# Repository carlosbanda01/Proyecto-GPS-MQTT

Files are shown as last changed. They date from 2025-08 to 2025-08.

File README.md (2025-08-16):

# Proyecto-GPS-CBC

Se desarrolló una solución de monitoreo GPS en tiempo real basada en una PCB personalizada que integra módulos SIM, GPS, relés, controladores I2C para pantallas LCD, reguladores de voltaje, comunicación SPI y microcontroladores ESP32 de doble núcleo con RTOS. La transmisión de datos hacia el servidor se implementó mediante el protocolo MQTT. Como complemento, se diseñó una plataforma web para la consulta y visualización de los datos almacenados, ofreciendo un sistema integral para supervisar y gestionar el funcionamiento de los equipos en operación.

---

### 🖼️ Placa de PCB diseñada

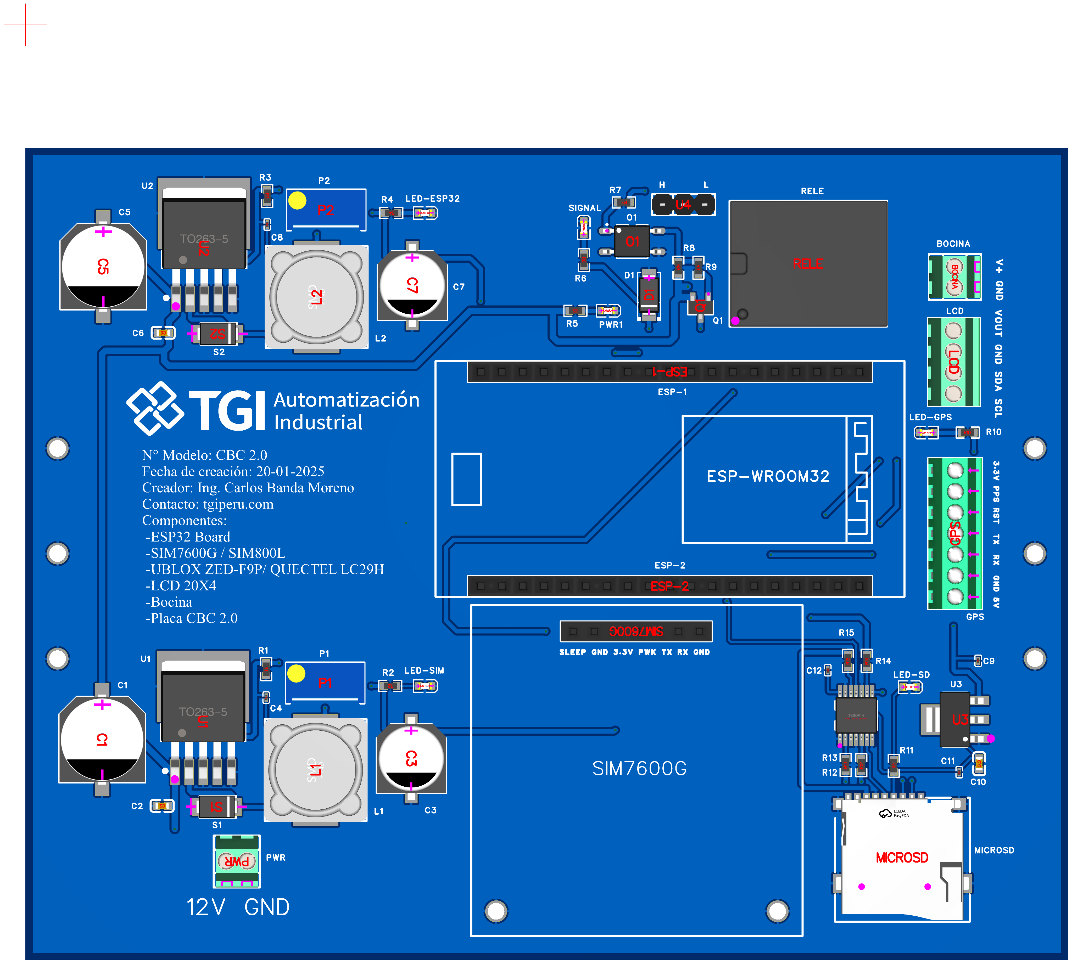
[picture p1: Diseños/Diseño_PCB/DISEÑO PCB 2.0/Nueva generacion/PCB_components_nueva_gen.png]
Diseño PCB Nueva Generación


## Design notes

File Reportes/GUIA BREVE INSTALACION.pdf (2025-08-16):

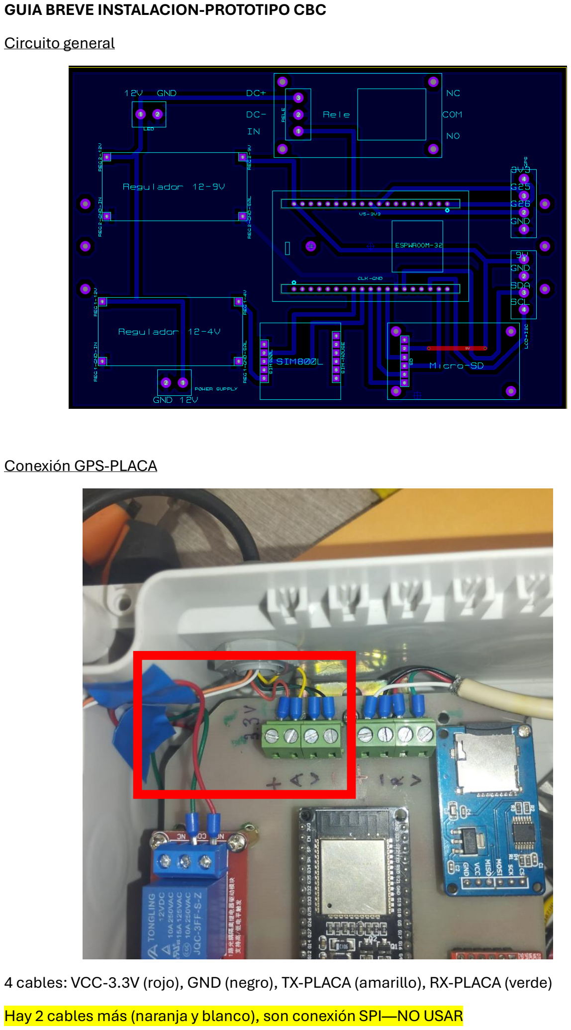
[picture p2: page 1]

GUIA BREVE INSTALACION-PROTOTIPO CBC Circuito general

Conexión GPS-PLACA

4 cables: VCC-3.3V (rojo), GND (negro), TX-PLACA (amarillo), RX-PLACA (verde) Hay 2 cables más (naranja y blanco), son conexión SPI—NO USAR

Conexión LCD-PLACA

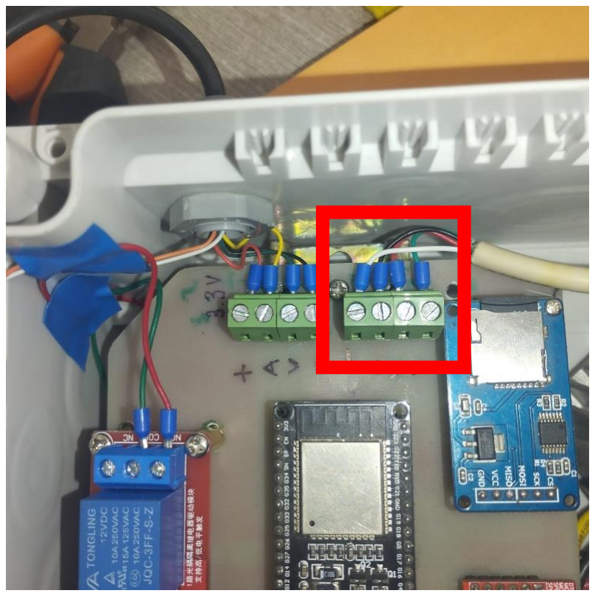
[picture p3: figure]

4 cables: VCC-(5-10)V (blanco), GND (negro). SDA (rojo) y SCL (verde)
En caso el cable quede muy largo, se sugiere cortar el cable por la parte cercana a la caja, pues NO SE RECOMIENDA abrir la caja metálica.
ASEGURARSE DE QUE LOS CABLES ESTEN FIJADOS A LAS BORNERAS
Conexión ALIMENTACIÓN-PLACA

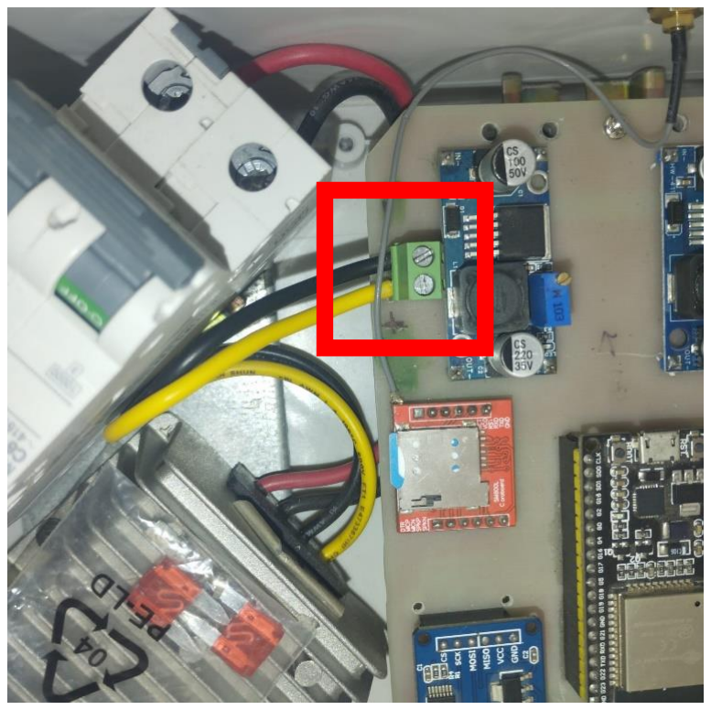
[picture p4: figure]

2 cables: VCC-12V (Amarillo) y GND (negro)
ASEGURARSE DE QUE LOS CABLES ESTEN FIJADOS A LAS BORNERAS

Conexión BUZZER-RELE-PLACA

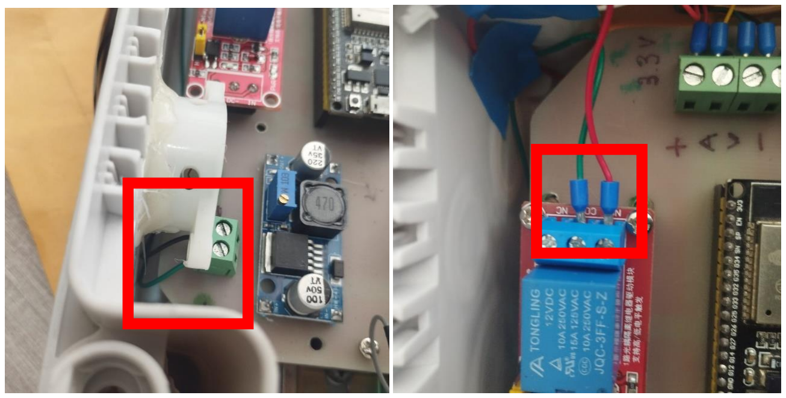
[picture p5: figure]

Del BUZZER hay 2 cables: VCC-(8-24V) (rojo) y GND (negro), el cable rojo del BUZZER se conecta a la bornera NO del RELÉ, por otro lado, el cable negro del BUZZER se conecta a la bornera verde superior de la PLACA.
ASEGURARSE DE QUE LOS CABLES ESTEN FIJADOS A LAS BORNERAS
Finalmente se conecta un cable verde que sirva como puente entre el positivo de la bornera verde de la PLACA con el COM del RELÉ.
Respecto al encendido del prototipo:
1. Encender el circuito
¿Qué se espera?
Que enciendan las 3 luces del circuito

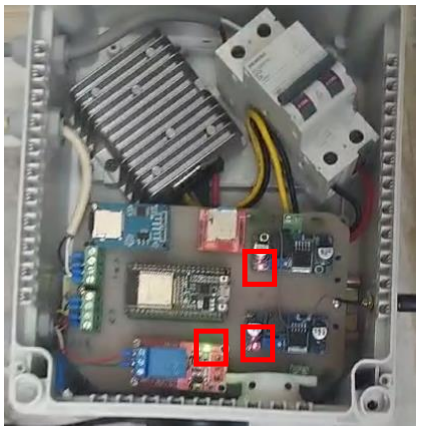
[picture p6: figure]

2. Activar la LCD
¿Qué se espera?
El mensaje de “Iniciando…” en el display seguido del mensaje “Esperando SIM800”

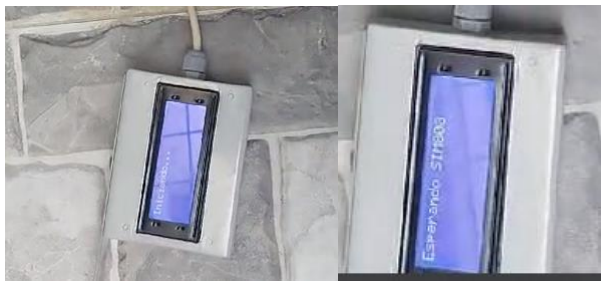
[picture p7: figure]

3. Activar el módulo SIM800L
¿Qué se espera?
El mensaje de “SIM800 iniciado” en el display

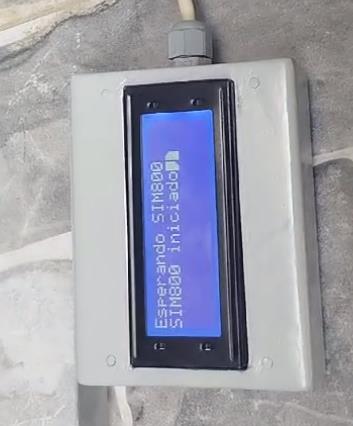
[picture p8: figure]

4. Conectarse a Internet (GPRS)
¿Qué se espera?
El mensaje de “Conectado a GPRS” en el display.
Normalmente este paso demora menos de 20 segundos en activarse, depende de la señal de la cobertura 2G, según la documentación de movistar en CBC toda el área tiene cobertura 2G.

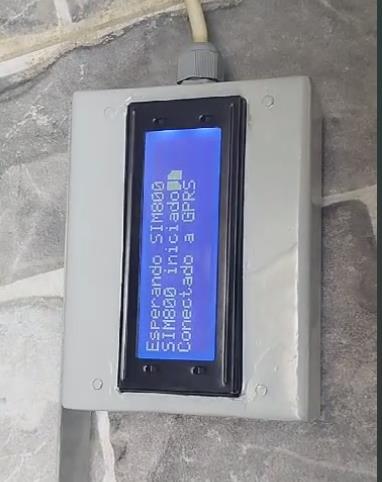
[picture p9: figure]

5. Conectarse al bróker ()
¿Qué se espera?
Recibir mensajes de modulo iniciado en el bróker. (un indicador verificable seria lo esperable del paso 6)
6. Activar la SD
¿Qué se espera?
El mensaje de “SD inicializada” en el display

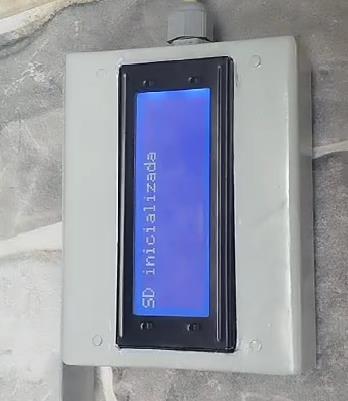
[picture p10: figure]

7. Conectarse a los satélites
¿Qué se espera?
Que desaparezca el mensaje de “Captando señal…” en el display
Normalmente este proceso demora entre 1-2 min cuando el prototipo se enciende tras mucho tiempo estar apagado.
8. Conectado
¿Qué se espera?
Que se muestre la velocidad (con una tasa de refresco de 1 segundo ) y que dichos datos se envíen al bróker mediante GPRS.

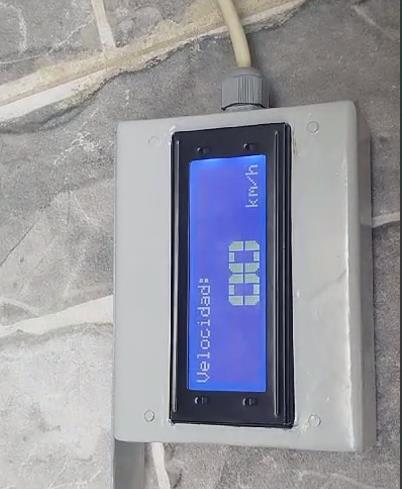
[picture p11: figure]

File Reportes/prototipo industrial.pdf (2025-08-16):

Presentación alternativas-Prototipo industrial CBC
1. PCB propia+ adaptadores Riel-DIN
PCB-propia
En lima se cuentan con servicios de impresión en PCB, en el software Proteus se puede diseñar las conexiones de la PCB con los componentes que ya se tienen y que irán dentro de la PCB (ESP32, REGULADOR DE VOLTAJE MODULO SIM7600G/800L, RELE, TARJETA microSD) como tal, además se contará con borneras para las conexiones con los componentes externos a la caja (GPS, PANTALLA LCD, BOCINA/LED que avise exceso de velocidad, FOCO LED que verifica energizado)

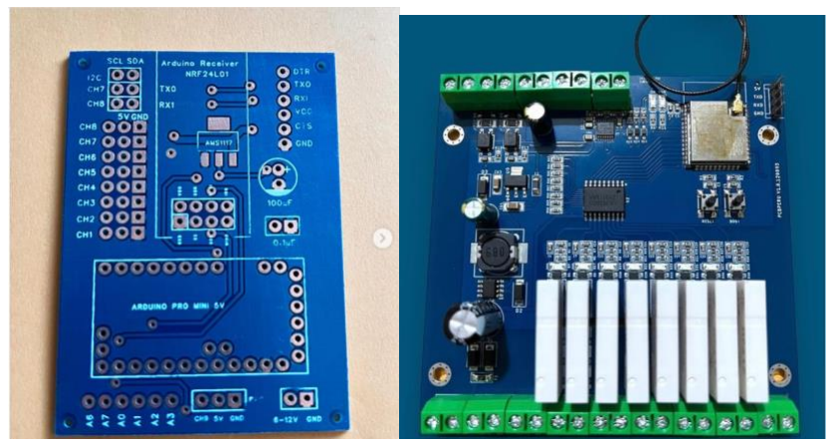
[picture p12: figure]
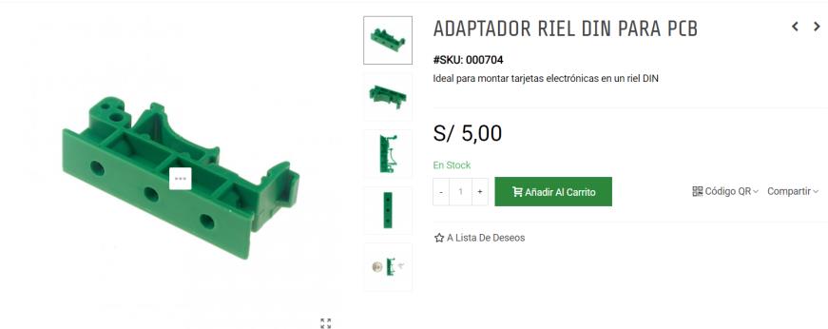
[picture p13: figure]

Cosas para considerar:
-Fácil acceso y compras que se pueden realizar rápido (todo está en stock y en lima) (a excepción del módulo SIM7600G)
-Es posible adquirir un módulo GNSS de menor generación como el SIM800L en Lima que son compatibles con el proyecto, sin embargo, este módulo funciona con cobertura 2G, que en un futuro será obsoleta y retirada.

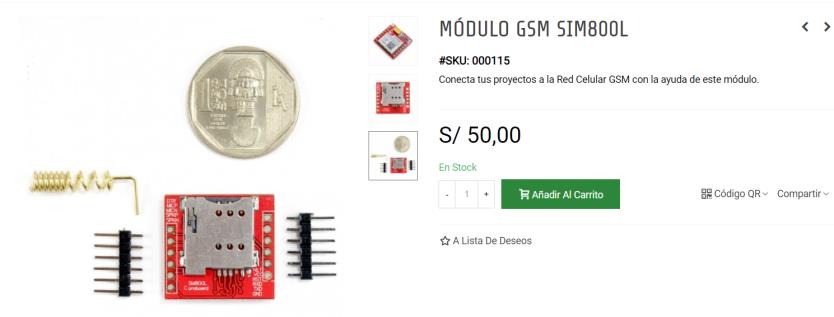
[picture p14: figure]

-Para conseguir el módulo SIM7600 o módulos similares se debe pedir y esperar durante un buen tiempo.
-Los módulos de última generación como los SIM7600,SIM7100C,SIM7670 y la lista sigue por mucho, algunos traen integrados ya en sus módulos comerciales, receptores GPS.

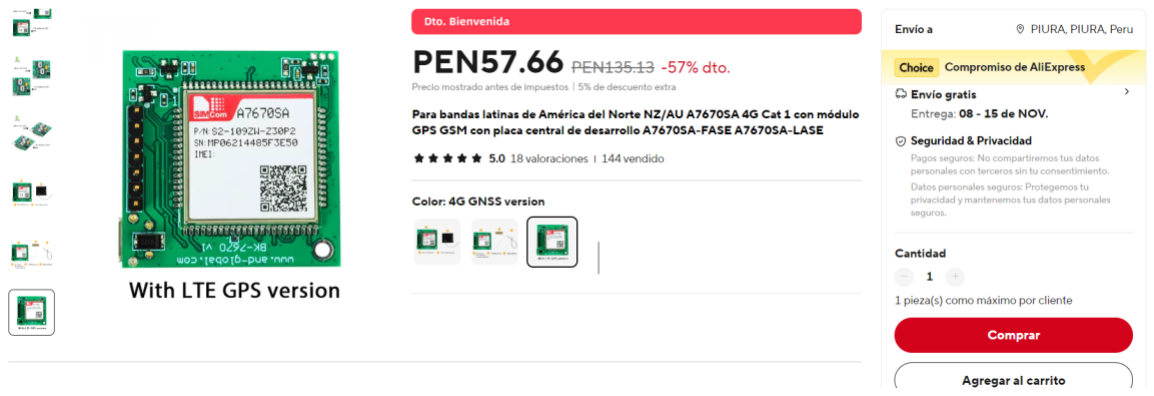
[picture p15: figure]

-Se requiere que al menos se suelden los componentes a la placa PCB -Se necesitaría hacer el diseño de la PCB
-Permite tener diseños personalizables

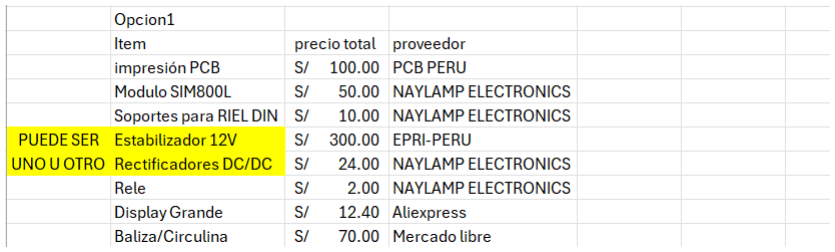
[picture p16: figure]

2. PCB’s experimentales++ adaptadores Riel-DIN
PCB-propia, se requiere al igual que en la opción 1, la fabricación de una PCB donde colocar la motherboard experimental, existen de muchos tipos y de muchas compatibilidades, a continuación, se presentan las principales:

Lily GO T-SIM7600E/G/SA-H
Posee: GPS integrado, SIM7600G-cobertura 2-4G+, Modulo TF-CARD/MicroSD, doble antena (principal y de apoyo), se puede cargar por medio de un panel solar, posee un compartimento para batería de litio de gran duración, se puede alimentar directamente mediante un rectificador/estabilizador en la conexión del panel.

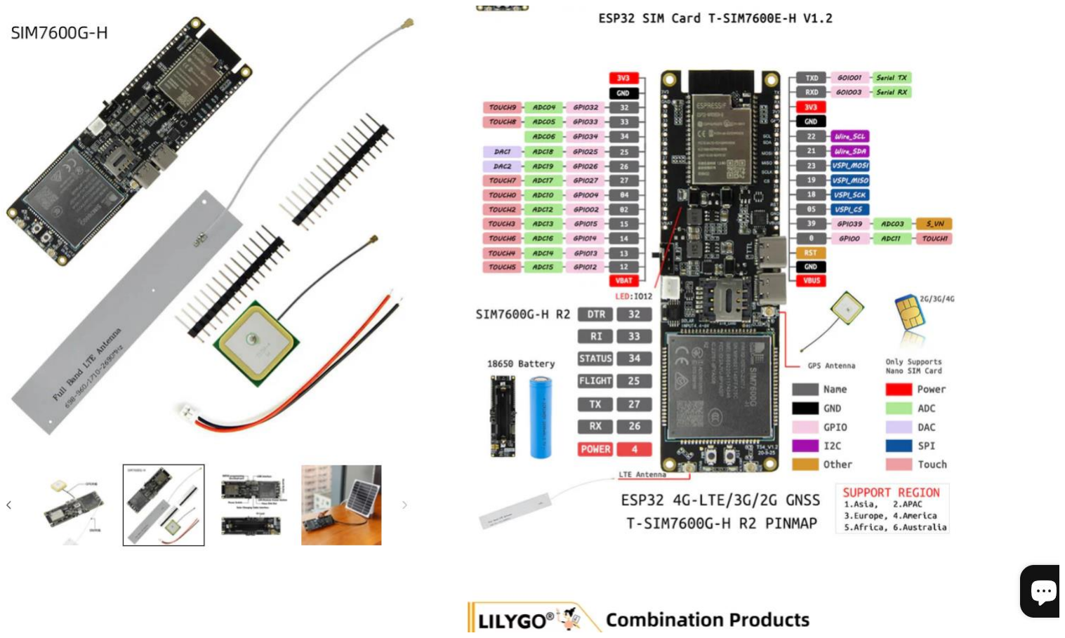
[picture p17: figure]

Y hay muchas más, muchísimas…
Mi opinión: probar la opción 1 en formato industrial, si la recepción no es lo suficientemente buena, probar con el SIM7600G o inclusive probar las placas de desarrollo de Lily Go.

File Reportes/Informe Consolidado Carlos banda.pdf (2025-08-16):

RUC 20530214762 | Teléfono +51 94 1905 773 | www.tgiperu.com

Piura, 27 de Febrero de 2025

INFORME N° 01-2025

Señores | : TGI Ingeniería EIRL
Atención | : Ing. Dantty Ramos Tene
Asunto | : Resumen de actividades
Proyecto | : Instalación de módulos GPS en Montacargas CBC-Sullana

Fecha de ejecución: Enero – Febrero 2025

De mi mayor consideración.

Por medio del presente, informo sobre los trabajos realizados referente al asunto. A continuación, se describen en detalle las actividades ejecutadas:

1. Diseño y fabricación del módulo GPS montable, incluyendo placa, soportes y componentes varios.
Se dimensiono componentes electrónicos acorde a los requisitos solicitados, así como de la disponibilidad del mercado local en base a criterios de ingeniería. (ver anexo 1)
2. Instalación del modulo GPS en los montacargas 02, 03 y 15 de CBC-Sullana

Se realizó la supervisión y apoyo de la instalación de los módulos GPS en CBC-Sullana. (ver anexo 2)

3. Programación y testeo del funcionamiento del Microcontrolador (ESP32)

Se programo y se testeo un código basado en lenguaje C++ para el funcionamiento del microcontrolador.

4. Soporte para fallas del modulo

Se brindo un monitoreo continuo al funcionamiento de los módulos GPS, levantando observaciones y realizando modificaciones en la arquitectura de su funcionamiento lógico y/o físico acorde a requerimientos del contratista.

5. Análisis de datos registrados
Se brindaron múltiples reportes de toda la data recogida, así como un análisis conciso respecto al estado y el significado de dicha información. (ver anexo 3)
6. Diseño de una PCB embebida.
Se diseño una PCB que adaptadara de forma embebida todos los módulos ya usados, brindando de mayor robustez y manipulabilidad al módulo GPS. (ver anexo 4)
7. Conclusiones

Tras las ultimas inspecciones realizadas se concluye que los módulos GPS montados se encuentran en condiciones funcionales, pero es necesaria una mejora de hardware para lograr los objetivos que se plantearon en un inicio.

Es necesario seguirle dándole soporte y monitoreo continuo a los módulos y su desempeño, especialmente a los servicios Postpago con los que se cuentan.

Se adjuntan las evidencias fotográficas antes mencionadas.

Atentamente,

Carlos Banda Moreno
DNI: 71410030

Anexo 1

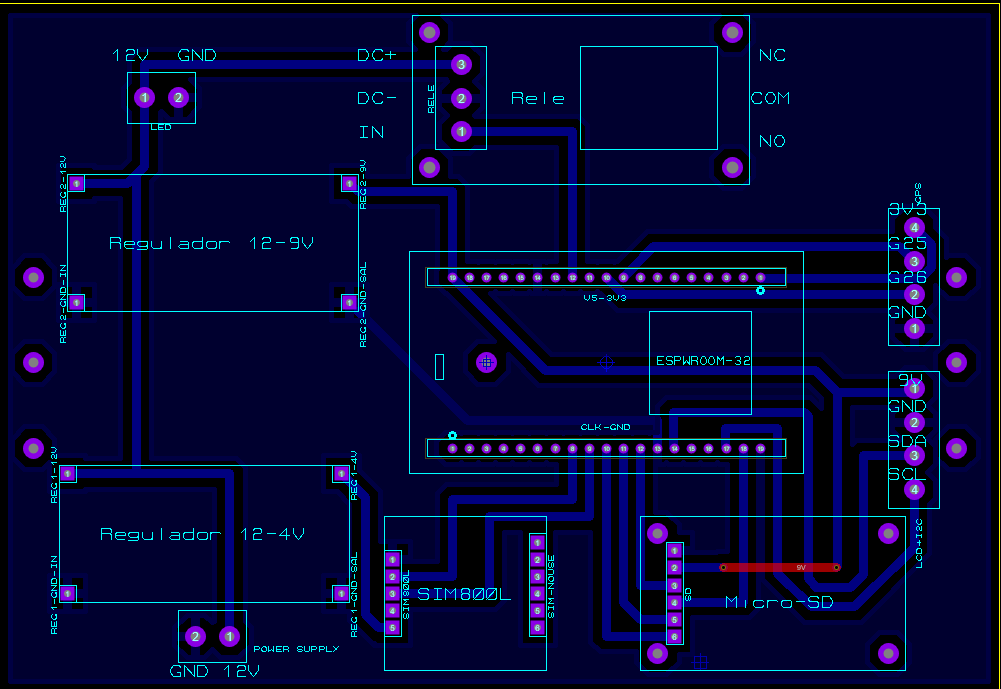
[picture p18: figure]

Anexo 2

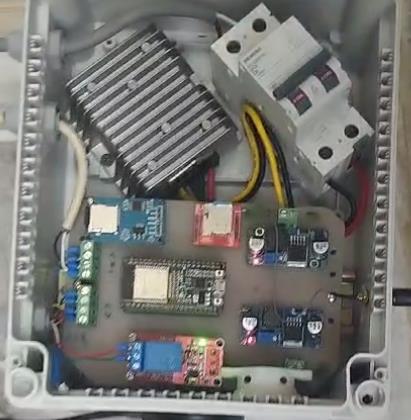
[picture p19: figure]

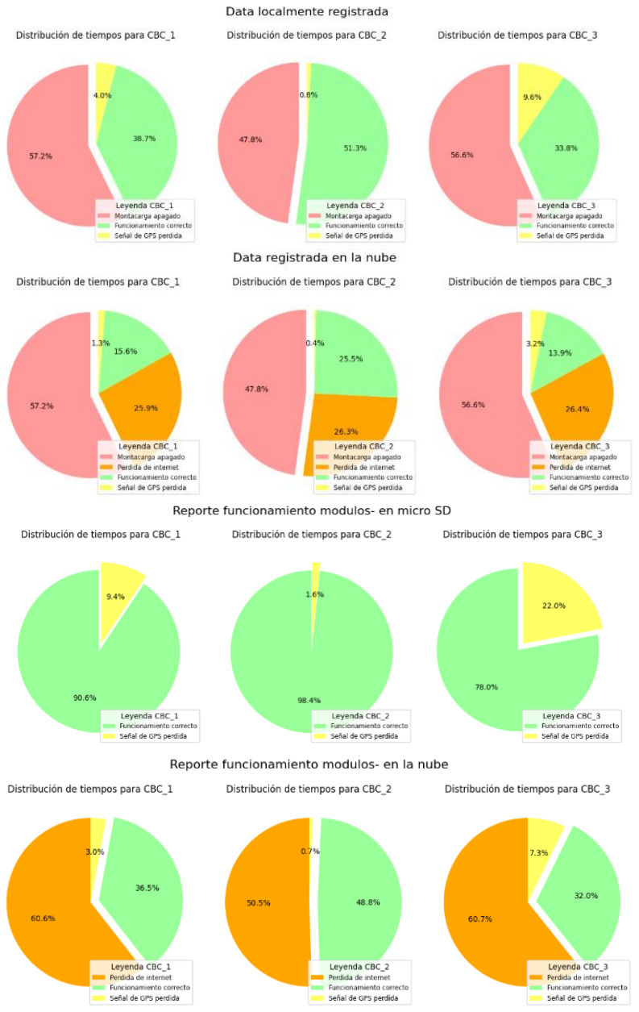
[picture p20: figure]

Anexo 3

Anexo 4

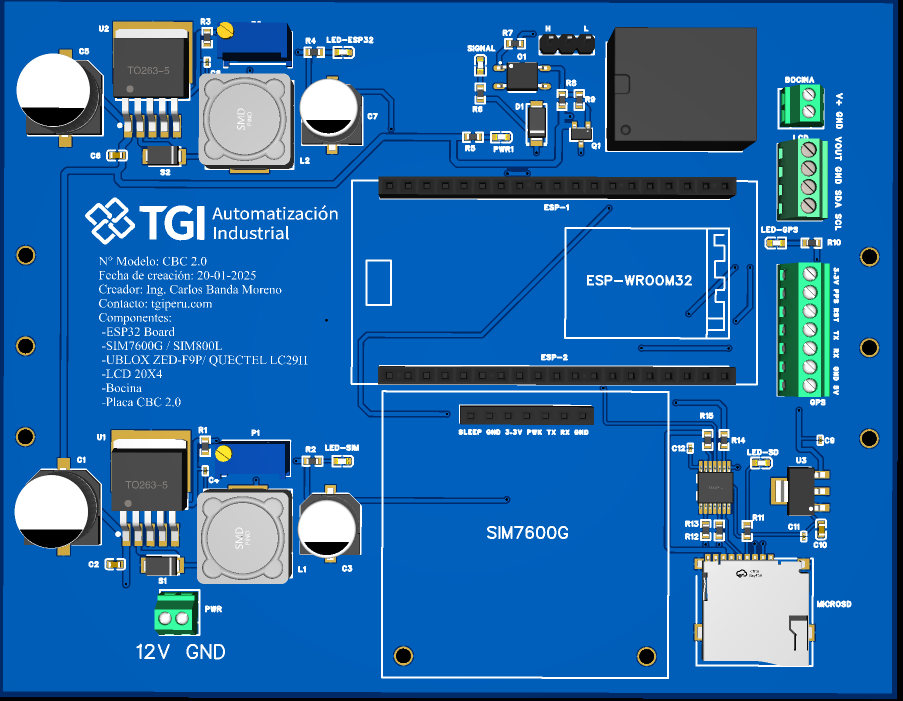
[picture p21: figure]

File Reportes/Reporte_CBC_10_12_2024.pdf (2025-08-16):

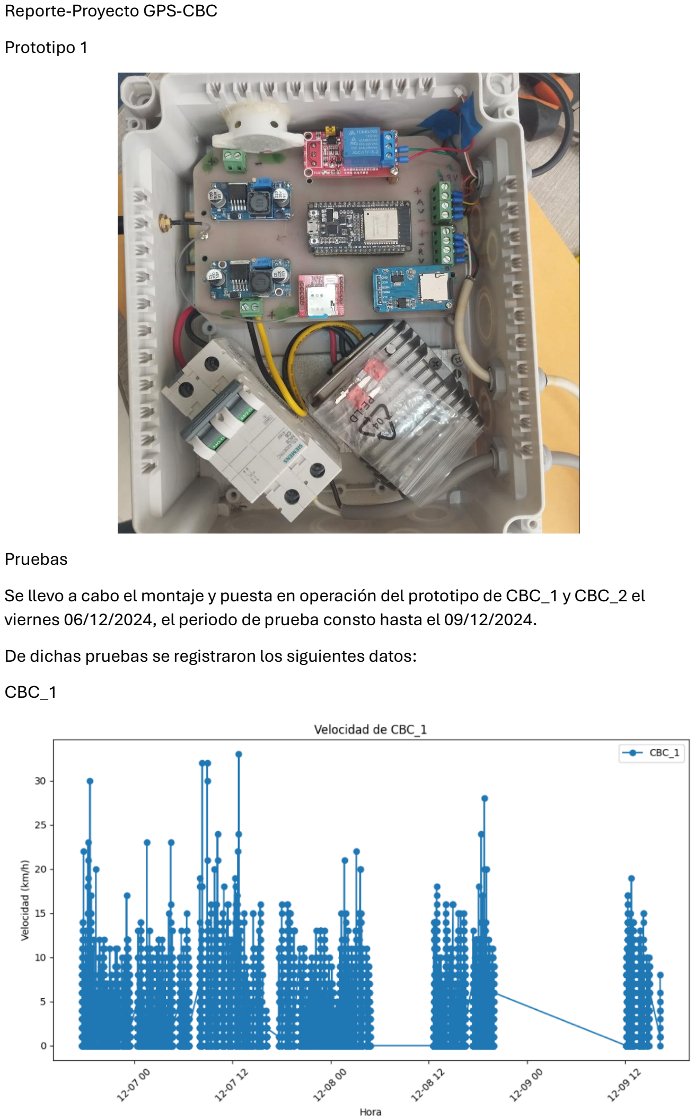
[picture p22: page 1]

Reporte-Proyecto GPS-CBC
Prototipo 1

Pruebas
Se llevo a cabo el montaje y puesta en operación del prototipo de CBC_1 y CBC_2 el viernes 06/12/2024, el periodo de prueba consto hasta el 09/12/2024.
De dichas pruebas se registraron los siguientes datos:
CBC_1

CBC_2

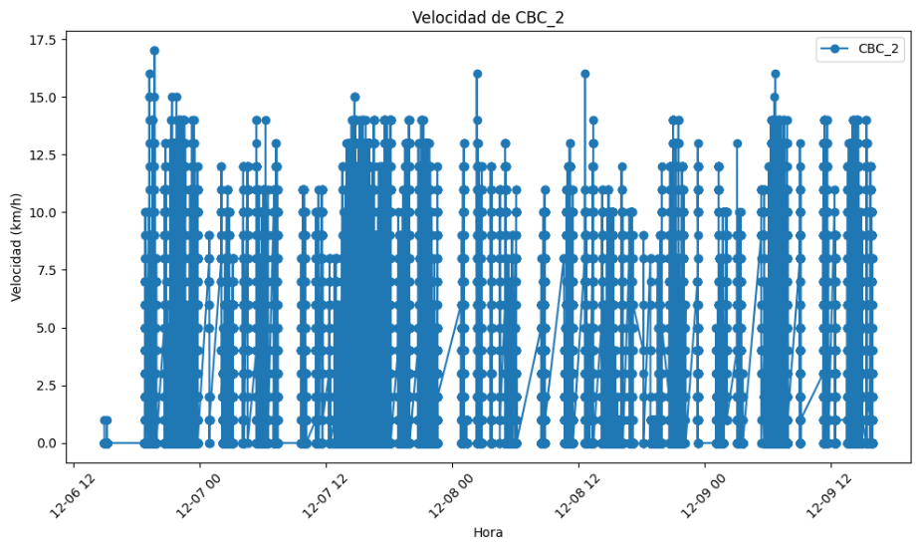
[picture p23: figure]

De los cuales se puede apreciar en ambos casos, lapsos de tiempo donde no se recibió datos del prototipo, siendo el hueco de datos mas apreciable el 08/12/2024 de casi 16 horas seguidas.
Análisis de fallos
Tras un monitoreo continuo y mediante un breve análisis del código subido se llegó a la conclusión que el problema surge cuando se pierde cobertura 2G, el código subido en ambos prototipos intenta conectarse una y otra vez a internet, intentos que llenan la memoria flash, generando un reiniciado en el prototipo. A continuación, se presenta una imagen referencial de las zonas donde se ha observado repetidamente la perdida de señal

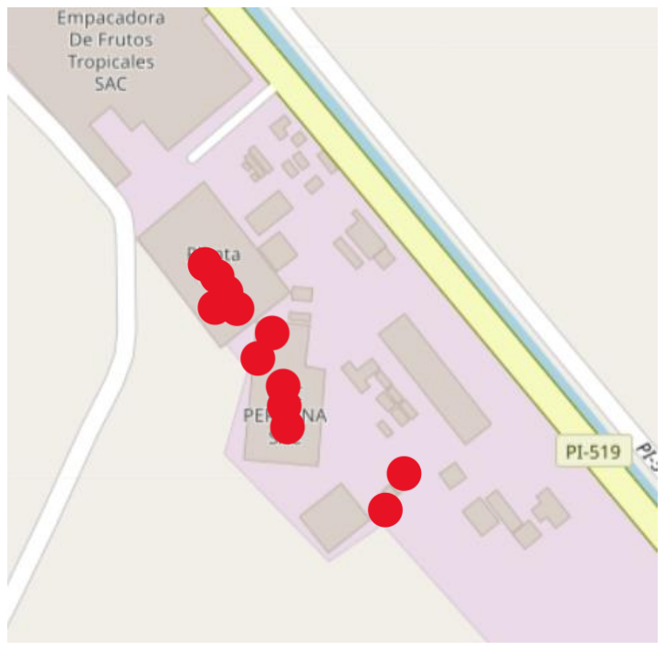
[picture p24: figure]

Soluciones sugeridas
1. Soporte 4G y 3G
Existen muchos módulos IoT con soporte para 4G y 3G, sin embargo, por temas de disponibilidad de mercado, así como periodo de envió y características, se considera que el módulo SIM7600G es el más adecuado, pues cuenta con:
- Soporte 4G y 3G
- Ubicación por GPRS
- Soporta protocolo SSL y permite cargar certificados de seguridad (necesario para conectarse a un bróker seguro personalizado).

Link del módulo:
https://es.aliexpress.com/item/4000449295553.html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 (https://es.aliexpress.com/item/4000449295553.html?utparam-url=scene%3Asearch%7Cquery_from%3A) https://es.aliexpress.com/item/1005006782779716.html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 (https://es.aliexpress.com/item/1005006782779716.html?utparam-url=scene%3Asearch%7Cquery_from%3A)
tienda de lima:
https://intecx.com.pe/product/modulo-sim7600g-4g-lte/
2. Módulos comunicadores de baja frecuencia
Como alternativa al prototipo actual se puede considerar reestructurar el proyecto para usar 2 tipos de comunicación: radiofrecuencia y datos móviles.
Desde los prototipos se instalaría módulos lora los cuales mediante señales de baja frecuencia se conectarían a una pc/Raspberry la cual se encargaría de gestionar la información y subirla en internet.
El módulo recomendado es el Módulo LoRa SX1278, de 918MHz.
Link:
https://es.aliexpress.com/item/1005001802601881.html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 (https://es.aliexpress.com/item/1005001802601881.html?utparam-url=scene%3Asearch%7Cquery_from%3A)
tienda en lima
https://www.electromania.pe/producto/modulo-inalambrico-lora-sx1278/https://www.teslaelectronic.com.pe/producto/modulo-lora-sx1278-433mhz/

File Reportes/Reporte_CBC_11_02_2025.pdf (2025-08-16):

Reporte CBC-Sullana 11/02/2025
Cambios realizados
-Actualización de códigos en los 3 montacargas
+Enviar la última posición cuando pierde señal GPS (para que se ponga en gris) +Enviar la velocidad en decimales (aporta suavidad a las curvas)
+Enviar la precisión en decimales (sirve para detectar mejor la caída de GPS) -Cambio de cajas
Montacargas 2 (CBC_1) antes

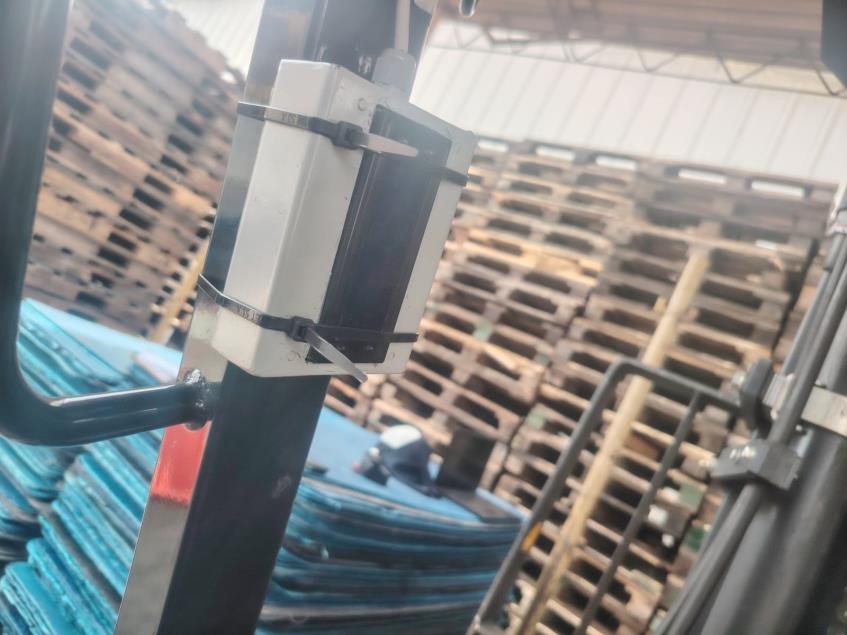
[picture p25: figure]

Montacargas 2 (CBC_1) después


Montacargas 3 (CBC_2) antes

Montacargas 3 (CBC_2) después

-Observaciones
+Se observa un posible golpe como causa de la caída de la caja de CBC_1


Se puede observar en la primera foto que la rotura ha elongado en vez de fracturarse de golpe (lo que sucedería si hubiera fallado por fatiga-vibración), además en las 2 figuras de abajo se observa que el soporte izquierdo (imagen de la izquierda) sobre el que se apoyaba el display tiene una desviación comparado con el soporte derecho (imagen de la derecha), el cual se encuentra mas recto y pegado al perfil cuadrado del montacarga.
+Se observa que las cajas están permitiendo que la humedad penetre y perjudique las placas PCB de los display, esto se observó en CBC_1 y CBC_2, y por ende es casi seguro que también este pasando en CBC_3


+Se observa que tanto el modulo rele de CBC_1 como el de CBC_2 se han malogrado y no pueden activar la bocina de alarma, el único indicador de exceso de velocidad es el display

Tras examinarlo, se determinó que la falla viene dado que las pistas se desgastaron mucho al momento de desoldarle las borneras y se manifestó debido a la vibración del montacargas. ES NECESARIO REEMPLAZAR AMBOS MODULOS (costo por und: 10 soles)

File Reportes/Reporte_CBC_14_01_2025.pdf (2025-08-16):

Reporte CBC-14/01/2025
Cambios realizados
- Actualización de códigos
Versión Previa (V 1.1.1) | Versión nueva (V 1.1.2)
No guardaba datos cuando pierde señal GPS (huecos) | Guarda datos vacíos cuando pierde señal GPS (Hora actual y ceros)
Mantiene la conexión a internet de manera constante (No evita estancamiento de datos) | Usa una conexión intermitente (Evita estancamiento de datos)
- Actividades futuras por realizar
Software | Impacto | Hardware | Impacto
Diseñar la placa PCB versión 2.0 | Disminuye el tamaño y mejora la integridad de las conexiones internas, reduce costos | Revisar la integridad de LCD-CBC_2 | Comprobar que las conexiones de LCD no han sido afectadas por las lluvias
Probar el funcionamiento del SIM7600G | Actividad necesaria para integrar el nuevo módulo SIM | Revisar la integridad de BOCINA/RELE-CBC_2 | Comprobar que la BOCINA o modulo RELE no han sido afectadas por las lluvias
Probar el funcionamiento del nuevo GPS | Actividad necesaria para integrar el nuevo módulo GPS | Integrar SIM7600G | Mejora la conexión a internet del modulo
Integrar los protocolos SSL | Añade una capa de encriptación a la data enviada, además permite acceder al bróker pagado de TGI | Integrar un mejor GPS | Mejora la zona de cobertura de los módulos
Integrar el soporte 3G, 4G y LTE | Mediante las pruebas al modulo SIM7600G se puede hacer esto. | Cambiar la caja de la pantalla de CBC1 | Aumentar la estabilidad frente a las vibraciones
Integrar geolocalización GPRS | Soporte secundario para no perder nunca la ubicación (no es tan precisa) | Cambiar la caja de la pantalla de CBC2 | Mejorar la localización de la bocina, para evitar daños por lluvia

- Imágenes de las actividades realizadas


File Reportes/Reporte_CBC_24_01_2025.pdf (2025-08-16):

Reporte CBC-23/01/2025
Cambios realizados
- Actualización de códigos
Versión Previa (V 1.1.2) | Versión nueva (V 1.1.3)
No funcionaba si el chip le cortaban la cobertura (el plan de datos no era pagado) | Funcionaba aun si el chip le cortaban la cobertura de datos
- Actividades realizadas
Tarea | Comentarios
Subir el código nuevo | Sin problemas
Revisar la integridad de la bocina de CBC_2 | El módulo relé ha quedado inoperativo debido a una pobre soldadura, la bocina sigue funcionando.
- Actividades futuras por realizar
Software | Impacto | Hardware | Impacto
Probar el funcionamiento del SIM7600G | Actividad necesaria para integrar el nuevo módulo SIM | Arreglar el módulo relé de CBC_2 | Volverá a estar operativa la función de alarma de CBC_2
Probar el funcionamiento del nuevo GPS | Actividad necesaria para integrar el nuevo módulo GPS | Integrar SIM7600G | Mejora la conexión a internet del modulo
Integrar los protocolos SSL | Añade una capa de encriptación a la data enviada, además permite acceder al bróker pagado de TGI | Integrar un mejor GPS | Mejora la zona de cobertura de los módulos
Integrar el soporte 3G, 4G y LTE | Mediante las pruebas al modulo SIM7600G se puede hacer esto. | Cambiar la caja de la pantalla de CBC1 | Aumentar la estabilidad frente a las vibraciones
Integrar geolocalización GPRS | Soporte secundario para no perder nunca la ubicación (no es tan precisa) | Cambiar la caja de la pantalla de CBC2 | Mejorar la localización de la bocina, para evitar daños por lluvia
Coordinar el funcionamiento de la página web | Aumenta la fluidez de datos

Con respecto a el funcionamiento de la pagina web es necesario especificar lo siguiente:
1. Es necesario que la página web/interfaz lea los datos desde una base de datos y no directamente desde el bróker.
2. La interfaz debe tener un retraso o desfase de al menos 1 minuto, esto es porque los datos dada la inestabilidad de red, a veces demoran un poco en llegar los datos y no siempre llegan al bróker 1 dato cada segundo.
Con respecto a la data revisada se tiene:
Se han registrado 10 días de datos


Grafica 1: datos locales contando huecos de hasta 2 segundos de duración
En cuanto a los datos registrados por la nube tenemos


Grafica 2: contando huecos de hasta 2 segundos de duración


Grafica 3: contando huecos de 5 segundos a mas


Grafica 4: contando huecos de 10 segundos a mas
I. Los montacargas han pasado casi el 50% del tiempo sin estar encendidos. II.

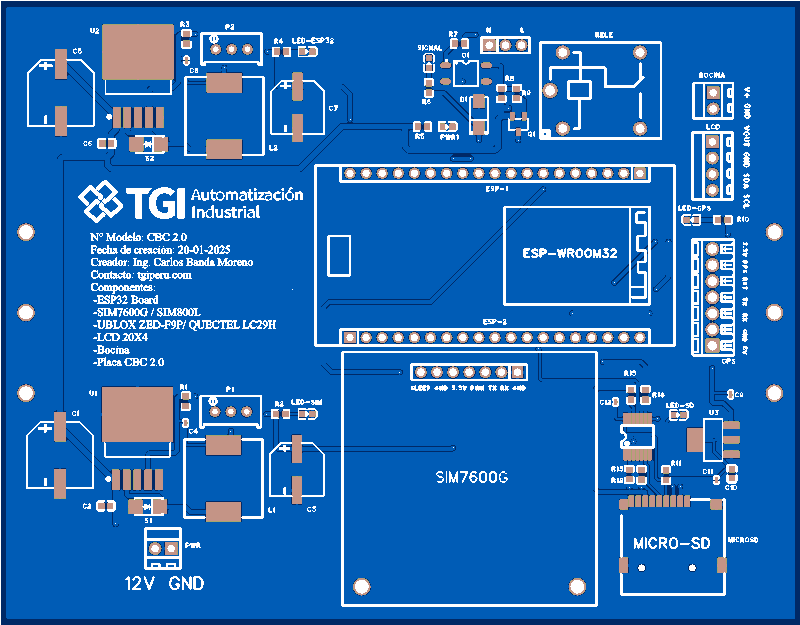
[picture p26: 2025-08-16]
Diseños/Diseño_PCB/DISEÑO PCB 2.0/Nueva generacion/PCB_nueva_gen.png

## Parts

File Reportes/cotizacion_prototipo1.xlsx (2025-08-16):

Cotizacion-Prototipo-GPS-CBC |  |  |  |  | Comprar todo en COSMOS
Item | Costo |  | Unidad | Total | Opcion1: LCD+I2C+MOLEX+pilas | Opcion2: LCD+I2C+APM+pilas | Opcion3: OLED+MOLEX+pilas | Opcion4: OLED+APM+pilas
 | COSMOS | ElectroPRO
Galleta perforada 7x9 | 3 |  | 2 | 6 | 104.6 | 111.5 | 111.6 | 118.5
Caja de electricidad 10x10x7 | 10 |  | 1 | 10
Set de espadines macho | 1 |  | 2 | 2
Set de espadines hembra | 1.5 |  | 2 | 3 | Comprar mezclado
Set de Jumpers | 6 |  | 1 | 6 | Opcion5: LCD+I2C+MOLEX+pilas | Opcion6: LCD+I2C+APM+pilas | Opcion7: OLED+MOLEX+pilas | Opcion8: OLED+APM+pilas
Modulo SD | 6 | 9 | 1 | 6
Pantalla opcion1: LCD+I2C | 21 | 15 | 1 | 21 | 98.6 | 105.5 | 101.6 | 108.5
Pantalla opcion2: OLED 0.91 pulgadas |  | 18 | 1
Pantalla opcion3: OLED de 0.96 pulgadas | 28 |  | 1 | 28
Conectores opcion 1: MOLEX |  |  |  |  | Si quitamos las pilas y los conectores: | Se reduce aprox 45 soles a todas las opciones
Conectores MOLEX de 4 pines (pareja) | 0.8 |  | 2 | 1.6
Conectores MOLEX de 2 pines (pareja) | 0.5 |  | 2 | 1 | Opcion recomendada: | Opcion1
Conectores opcion 2: APM
Conectores APM de 2 pines (pareja) | 1.5 |  | 2 | 3 | IMPORTANTE
Conectores APM de 3 pines (pareja) | 2 |  | 2 | 4
Conectores APM de 6 pines (pareja) | 2.5 |  | 1 | 2.5 | Precio referencial (SODIMAC)
Soporte PILAS x3 AAA | 3 |  | 1 | 3
Alimentacion opcion 1: pilas AAA DURACELL | 13 |  | 3 | 39
Alimentacion opcion 2: Bateria 3.7V 2600mA | 15 |  | 1 | 15
Soportes | 1.5 |  | 4 | 6

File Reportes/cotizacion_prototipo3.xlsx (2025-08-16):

 |  | TODOS LOS PRECIOS ESTAN EN SOLES
Cotizacion
opcion 1 | precio local | link | precio internacional | link
Modulo SIM7600G | 312 | https://intecx.com.pe/product/modulo-sim7600g-4g-lte/ | ~110 | https://es.aliexpress.com/item/4000078222573.html?utparam-url=scene%3Asearch%7Cquery_from%3A
 |  |  |  | https://es.aliexpress.com/item/4000449295553.html?utparam-url=scene%3Asearch%7Cquery_from%3A
 |  |  |  | https://es.aliexpress.com/item/1005006782779716.html?utparam-url=scene%3Asearch%7Cquery_from%3A
opcion 2 (modulos LoRa + server local): la desestime porque requiere comprar una minipc o rasp para la gestion de subida de datos, ademas requiere modificar el codigo en gran parte
Materiales necesarios para un 3er prototipo que sirve para probar codigo en futuros avances | Costo | link | observaciones
1 modulo SIM800L | 50 | https://naylampmechatronics.com/inalambrico/115-modulo-gsm-sim800l-2g.html | No hay en el mercado local, Sí es necesario para pruebas estaticas
1 gps UBLOX-8M | 92.5 | https://www.electromania.pe/producto/gps-ublox-neo-8m/ | No esta encapsulado, No es necesario para pruebas estaticas
1 estabilizador industrial | 300 | https://epriperu.com/productos/estabilizador-dc-dc-8v-40v-a-12v-10amp | No es necesario para pruebas estaticas
1 pantalla LCD 20x4 | 30 | https://naylampmechatronics.com/lcd-alfanumerico/158-display-alfanumerico-lcd-2004-5v-azul.html | Sí es necesario para pruebas estaticas
1 modulo RELE 12VDC | 6 | https://www.teslaelectronic.com.pe/producto/modulo-relay-1-canal/ | Sí es necesario para pruebas estaticas, se recomienda comprar varias unidades (min 2)

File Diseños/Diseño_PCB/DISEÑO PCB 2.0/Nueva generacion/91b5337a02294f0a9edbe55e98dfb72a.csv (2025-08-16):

No. | Quantity | Comment | Designator | Footprint | Value | Manufacturer Part | Manufacturer | Supplier Part | Supplier
1 | 2 | DB125-2.54-2P-GN-S | BOCINA,PWR | CONN-TH_DB125-2.54-2P-GN |  | DB125-2.54-2P-GN-S | DORABO(地博电气) | C918120 | LCSC
2 | 2 | 220uF | C1,C5 | CAP-SMD_BD10.0-L10.3-W10.3-LS11.3-FD | 220uF | UWT1H221MNL1GS | Nichicon(尼吉康) | C125977 | LCSC
3 | 2 | 100nF | C2,C6 | C0603 | 100nF | CGA0603X7R104K500JT | HRE(芯声) | C6119867 | LCSC
4 | 2 | 220uF | C3,C7 | CAP-SMD_BD8.0-L8.3-W8.3-FD | 220uF | HV221M035F105ETR | CapXon(丰宾) | C59926 | LCSC
5 | 5 | 100nF | C4,C8,C9,C11,C12 | C0201 | 100nF | GRM033C80J104KE15D | muRata(村田) | C415519 | LCSC
6 | 1 | 10uF | C10 | C0603 | 10uF | CGA0603X5R106K100JT | HRE(芯声) | C6119842 | LCSC
7 | 1 | 74LVC125APW,118 | Chip-logico-MicroSD | TSSOP-14_L5.0-W4.4-P0.65-LS6.4-BL |  | 74LVC125APW,118 | Nexperia(安世) | C6059 | LCSC
8 | 1 | 1N4007 | D1 | SMA_L4.3-W2.5-LS5.0-RD |  | 1N4007 | TWGMC(台湾迪嘉) | C727081 | LCSC
9 | 2 | PM254-1-19-Z-8.5 | ESP-1,ESP-2 | HDR-TH_19P-P2.54-V-F |  | PM254-1-19-Z-8.5 | HCTL(华灿天禄) | C2897382 | LCSC
10 | 1 | XY308-2.54-7P | GPS | CONN-TH_XY308-2.54-7P |  | XY308-2.54-7P | XINLAIYA(新莱亚) | C915916 | LCSC
11 | 2 | 470uH | L1,L2 | IND-SMD_L12.3-W12.3_SMDRI127 | 470uH | CYH127-470UH | SHOU HAN(首韩) | C2929509 | LCSC
12 | 1 | DB125-2.54-4P-GN-S | LCD | CONN-TH_DB125-2.54-4P-GN |  | DB125-2.54-4P-GN-S | DORABO(地博电气) | C918122 | LCSC
13 | 6 | NCD0603W1 | LED-ESP32,LED-GPS,LED-SD,LED-SIM,PWR1,SIGNAL | LED0603-RD |  | NCD0603W1 | 国星光电 | C84265 | LCSC
14 | 1 | TF-CARD H1.8 | MICROSD | TF-SMD_TF-CARD-H1.8 |  | TF-CARD H1.8 | SHOU HAN(首韩) | C7529389 | LCSC
15 | 1 | LTV-354T | O1 | SOP-4_L4.4-W3.9-P2.54-LS7.0-TL |  | LTV-354T | LITEON(光宝) | C119090 | LCSC
16 | 2 | 10kΩ | P1,P2 | RES-ADJ-TH_3P-L10.0-W10.0-P2.50-L | 10kΩ | 3296W-1-103 | BOCHEN(博晨) | C118954 | LCSC
17 | 1 | S8550 | Q1 | SOT-23-3_L2.9-W1.6-P1.90-LS2.8-BR |  | S8550 | Hottech(合科泰) | C181159 | LCSC
18 | 2 | 330Ω | R1,R3 | R0603 | 330Ω | FRC0603J331 TS | FOJAN(富捷) | C2907152 | LCSC
19 | 4 | 1kΩ | R2,R4,R10,R11 | R0603 | 1kΩ | FRC0603J102 TS | FOJAN(富捷) | C2907113 | LCSC
20 | 3 | 2.2kΩ | R5,R6,R9 | R0603 | 2.2kΩ | 0603WAF2201T5E | UNI-ROYAL(厚声) | C4190 | LCSC
21 | 2 | 10kΩ | R7,R8 | R0603 | 10kΩ | FRC0603J103TS | FOJAN(富捷) | C2930027 | LCSC
22 | 4 | 3.3kΩ | R12,R13,R14,R15 | R0603 | 3.3kΩ | FRC0603F3301TS | FOJAN(富捷) | C2907023 | LCSC
23 | 1 | JQC-3FF/12VDC-1ZS(551) | RELE | RELAY-TH_HF3FF-XX-1ZXX-XXX |  | JQC-3FF/12VDC-1ZS(551) | HF(宏发) | C46485 | LCSC
24 | 2 | SS34-MS | S1,S2 | DO-214AC_L4.3-W2.7-LS5.0-RD |  | SS34-MS | MSKSEMI(美森科) | C2836396 | LCSC
25 | 1 | PM254V-11-07-H85 | SIM7600G | HDR-TH_7P-P2.54-V-F |  | PM254V-11-07-H85 | XFCN(兴飞) | C2832270 | LCSC
26 | 2 | LM2596S-ADJ(UMW) | U1,U2 | TO-263-5_L10.2-W8.9-P1.70-BR |  | LM2596S-ADJ(UMW) | UMW(友台半导体) | C347423 | LCSC
27 | 1 | AMS1117-3.3 | U3 | SOT-223-3_L6.7-W3.7-P2.30-LS7.0-BR |  | AMS1117-3.3 | JSMSEMI(杰盛微) | C917183 | LCSC
28 | 1 | PZ254V-11-03P | U4 | HDR-TH_3P-P2.54-V-M |  | PZ254V-11-03P | XFCN(兴飞) | C2937625 | LCSC

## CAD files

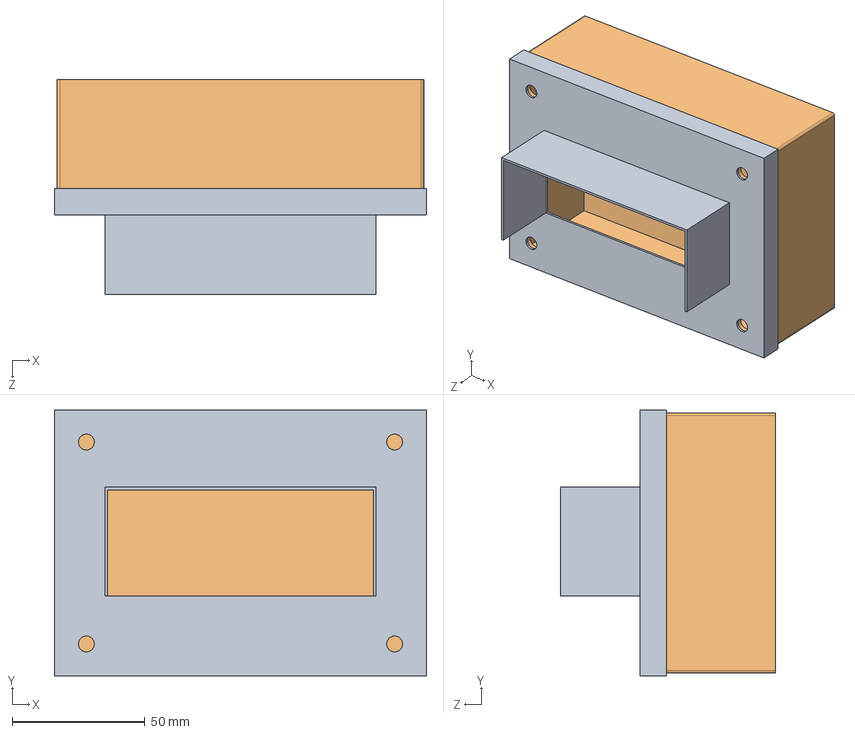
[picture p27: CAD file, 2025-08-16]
Diseños/Diseño_caja_LCD/CAJAMODEL1.SLDASM
140.0 x 100.0 x 81.0 mm
CAJA
TAPA

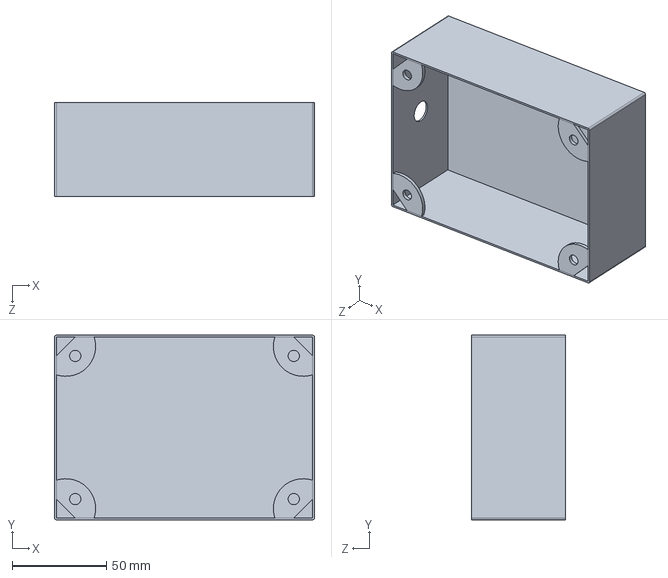
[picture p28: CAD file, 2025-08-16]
Diseños/Diseño_caja_LCD/CAJA.SLDPRT
138.0 x 98.0 x 50.0 mm

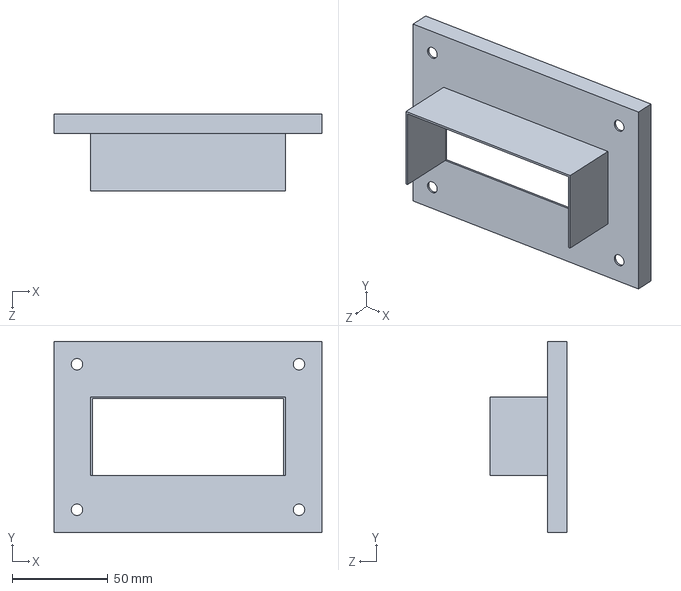
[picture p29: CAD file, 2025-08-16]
Diseños/Diseño_caja_LCD/TAPA.SLDPRT
140.0 x 100.0 x 40.0 mm

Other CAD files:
Diseños/Diseño_caja_LCD/CAJA.SLDDRW
Diseños/Diseño_caja_LCD/CAJAMODEL1.SLDDRW

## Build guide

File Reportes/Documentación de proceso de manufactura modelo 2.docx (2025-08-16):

Documentación de proceso de manufactura modelo 2.0-CBC

Selección de componentes

Componente | Parámetros críticos | | | | Comentarios
| Corriente máxima | Corriente operativa | Voltaje máximo | Voltaje operativo
ESP32 | 800 mA | 300-400 mA | 12V | 3.3V | Se selecciono un regulador que no soporte mas de 500 mA, a fin de proteger la placa

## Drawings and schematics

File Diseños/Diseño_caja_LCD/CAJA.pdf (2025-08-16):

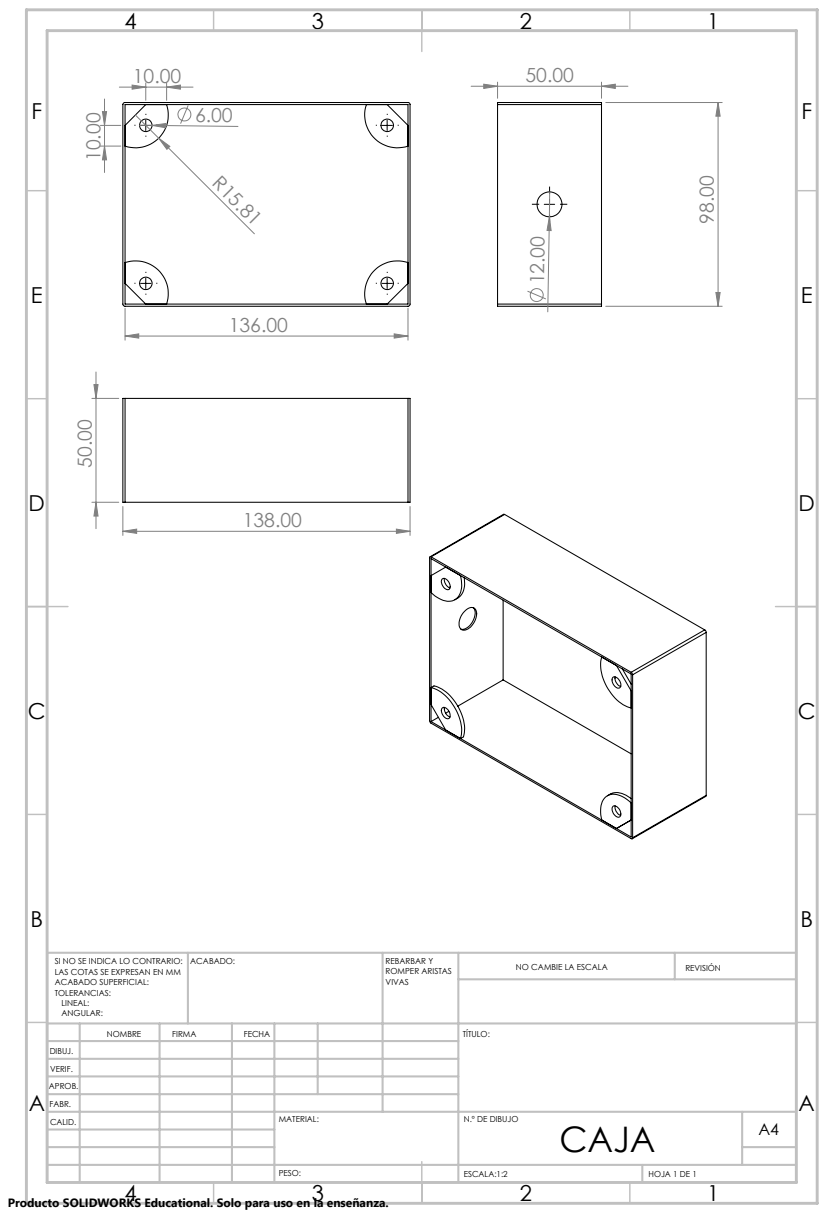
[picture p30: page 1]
ACABADO:; REBARBAR Y; ROMPER ARISTAS; NO CAMBIE LA ESCALA; REVISIÓN; ESCALA:1:2; HOJA 1 DE 1

SI NO SE INDICA LO CONTRARIO:
LAS COTAS SE EXPRESAN EN MM
ACABADO SUPERFICIAL:
TOLERANCIAS:
LINEAL:
ANGULAR:

NOMBRE | FIRMA | FECHA | | | | TÍTULO:

DIBUJ.
VERIF.
APROB.
FABR.
CALID. | | | | MATERIAL: | N.º DE DIBUJO CAJA | A4

Producto SOLIDWORKS Educational. Solo para uso en la enseñanza.

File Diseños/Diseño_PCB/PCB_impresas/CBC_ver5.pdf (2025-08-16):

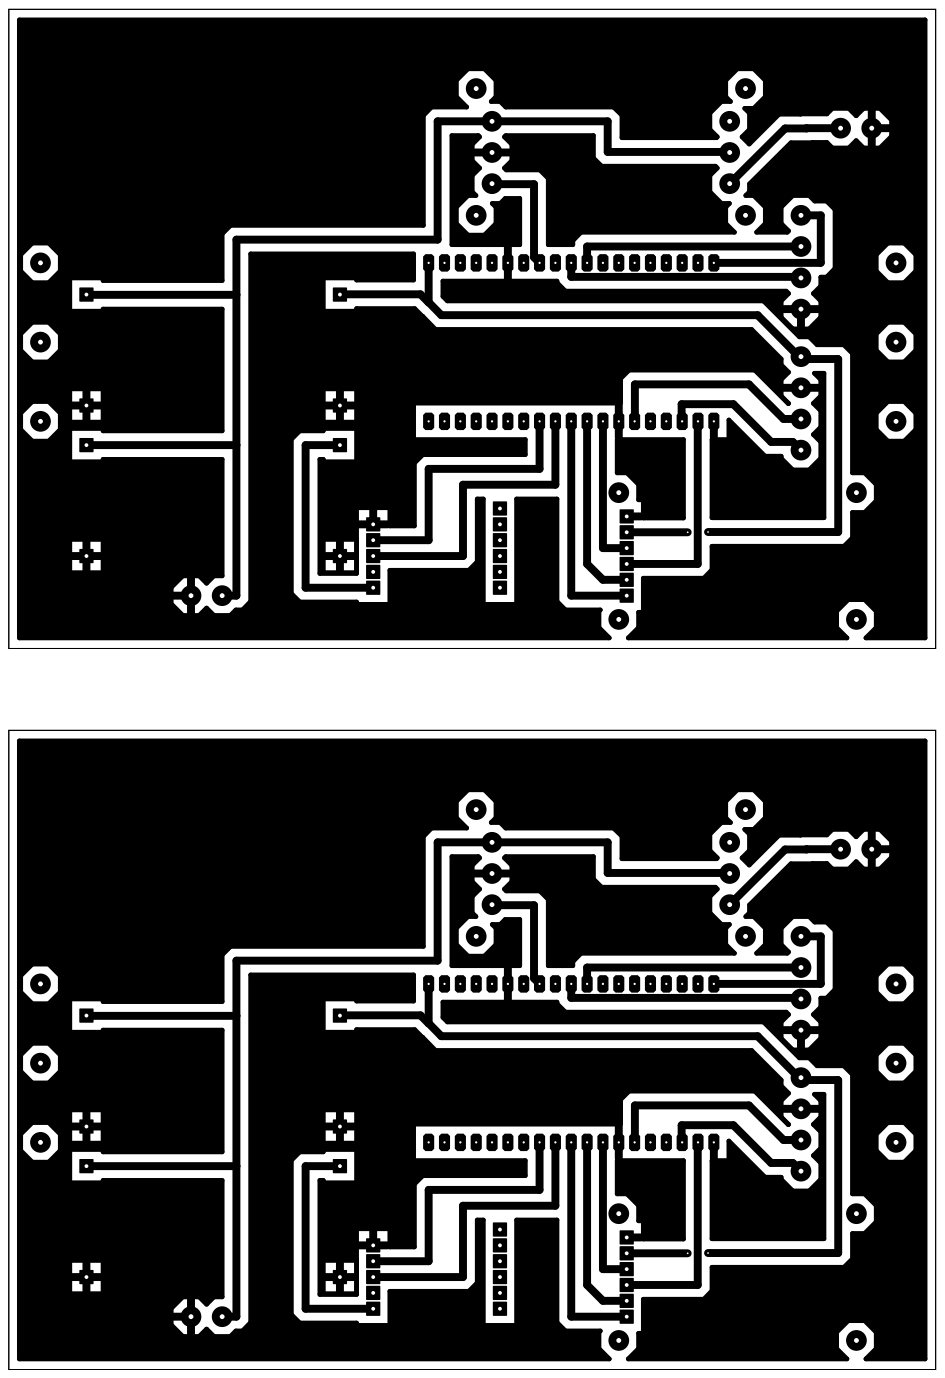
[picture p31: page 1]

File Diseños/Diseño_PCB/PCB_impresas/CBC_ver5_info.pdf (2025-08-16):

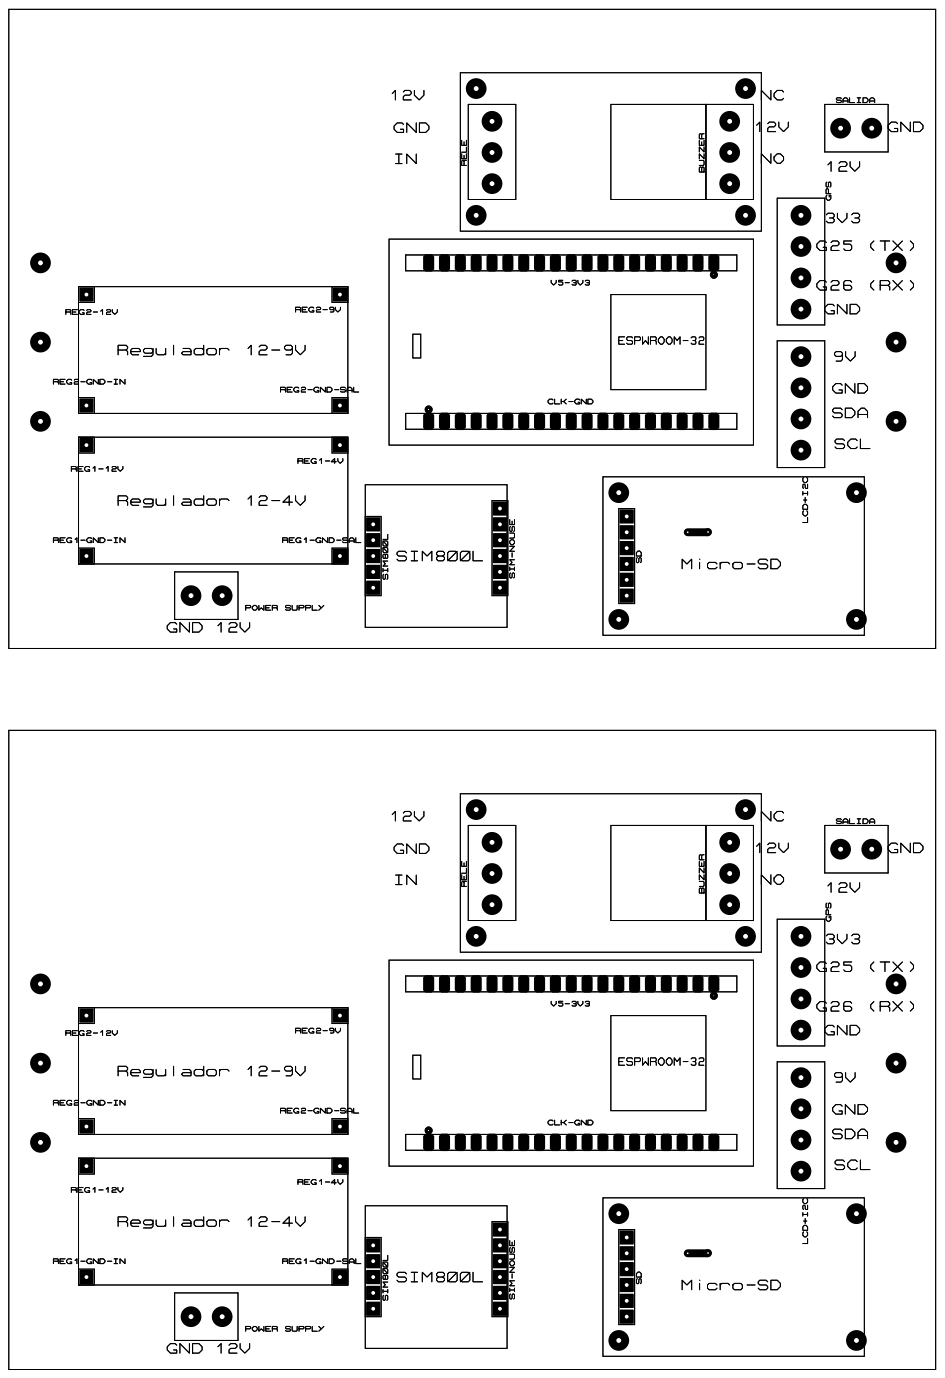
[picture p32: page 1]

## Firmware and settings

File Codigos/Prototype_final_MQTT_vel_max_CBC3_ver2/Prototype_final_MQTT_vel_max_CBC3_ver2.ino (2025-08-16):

#define SERIAL_RX_BUFFER_SIZE 1024
#define TINY_GSM_MODEM_SIM800
#include <TinyGPSPlus.h>//para entender la trama recibida del GPS
#include <HardwareSerial.h>//para los buses UART-GPS
#include <Wire.h>
#include <SPI.h>
#include <LiquidCrystal_I2C.h>  // Para la pantalla LCD
#include <SD.h>  // Para la tarjeta SD
#include <BigFont01_I2C.h>
#include <PubSubClient.h>
#include <TinyGsmClient.h>
#include <ArduinoJson.h>
#include <Preferences.h>
#include <regex>

LiquidCrystal_I2C lcd(0x27, 20, 4);  // Pantalla LCD 20x4
BigFont01_I2C big(&lcd);

Preferences preferences; //objeto preferences para recordar el tiempo

// Configuración de los pines de la comunicacion con el GPS
  static const int GPSRXPin = 26;  // Pin RX en el ESP32
  static const int GPSTXPin = 25;  // Pin TX en el ESP32
  static const uint32_t GPSBaud = 9600;  // Velocidad de comunicación del GPS

// Configuración de los pines de la comunicacion con el SIM800L
  static const int SIMRXPin = 16;  // Pin RX en el ESP32
  static const int SIMTXPin = 17;  // Pin TX en el ESP32
  static const uint32_t SIMBaud = 115200;  // Velocidad de comunicación del SIM

// Pines para la tarjeta SD
SPIClass spiSD(HSPI);  // nueva clase de SPI

// El objeto TinyGPSPlus
TinyGPSPlus gps;

// Usar Serial2 para la conexión con el GPS
HardwareSerial ss(2);  // Usamos UART2 del ESP32 (RX26,TX25)

//Usaremos Serial1 para la conexion con el SIM800L
HardwareSerial sim800(1);  // Usamos UART1 del ESP32 (RX16,TX17)

//Funcion para determinar el area:
  // Definir los vértices del polígono como pares (latitud, longitud)
  const int numVerticesArea1 = 12;  // Número de vértices en el polígono
  float area1_latitudes[] = {-4.928024, -4.928935, -4.929426, -4.92947, -4.928583, -4.928535, -4.928357, -4.928233, -4.928123, -4.927939, -4.927852, -4.927458};  // Coordenadas de latitud
  float area1_longitudes[] = {-80.633414, -80.632668, -80.632724, -80.632165, -80.632069, -80.632619, -80.63242, -80.632527, -80.632376, -80.632516, -80.632392, -80.632712};  // Coordenadas de longitud

  //definir la funcion q dara 0 y 1 depndiendo del area 1 y area 2
  bool isPointInPolygon(float pointLat, float pointLng, float* latitudes, float* longitudes, int numVertices) {
    bool inside = false;
    for (int i = 0, j = numVertices - 1; i < numVertices; j = i++) {
      if (((latitudes[i] > pointLat) != (latitudes[j] > pointLat)) &&
          (pointLng < (longitudes[j] - longitudes[i]) * (pointLat - latitudes[i]) / (latitudes[j] - latitudes[i]) + longitudes[i])) {
        inside = !inside;
      }
    }
    return inside;
  }

  //Declaramos la variable inside_area1
  bool insideArea1 = false;  // Variable global

//Declaramos el pinvelocidad 
  const int ledvel = 14;
//Contadores
  int attempt_connect_count = 0;
  int attempt_apn_count = 0;
  int max_attempts = 3;

//String dataString para guardar datos en CSV
  String dataString="";

//Configuracion APN:
  const char* APN = "movistar.pe";//chip.entel.pe para entel y claro.pe para claro movistar.pe pa movistar
  const char* USER = "movistar@datos";// "" para entel y claro, movistar@datos pa movistar
  const char* PWD = "movistar";// "" para entel y claro, movistar para movistar

// Configuración del broker MQTT (PLANTILLA - REEMPLAZAR CON DATOS REALES)
const char* mqtt_server   = "mqtt.example.com";   // Dirección del broker
const int   mqtt_port     = 1883;                 // Puerto (ej. 1883 sin TLS, 8883 con TLS)
const char* mqtt_user     = "usuario";            // Usuario de autenticación
const char* mqtt_password = "clave123";           // Contraseña de autenticación
const char* client_id     = "device_01";          // ID único para el cliente

// Tópicos MQTT
const char* topic1   = "planta/gps/datareceived/device_01"; // Datos en tiempo real
const char* topic2   = "planta/gps/datasend";               // Configuración (ej. vel_max)
const char* topic3   = "planta/gps/historyconsult";         // Consultas de históricos
const char* topic4   = "planta/gps/historydata/device_01";  // Respuesta de históricos
const char* topic5   = "planta/gps/deleteSD";               // Borrar SD
const char* topic6   = "planta/gps/stateESP32/device_01";   // Estado del dispositivo
const char* topiclwt = "planta/gps/off/device_01";          // Last Will Topic
const char* lwt      = "device_01 off";                     // Last Will Message

//Creamos la tarea Task2
  TaskHandle_t Task2;

//Nombre de los archivos a guardar en la SD y la clave de borrado
  String fileName = "/gps_data_"+String(client_id)+".csv";
  String velFile = "/vel_max_"+String(client_id)+".txt";
  String report_fail="/failures_"+String(client_id)+".txt";
  String tempFileName = "/temp.csv"; // Nombre del archivo temporal para la funcion deleteSD()
  String del_SD = "Delete_TGI"; //clave para autorizar el borrado de datos

//variables de recepcion para topic2, topic3 y topic5
  bool new_vel_max= false;
  int vel_in_max= 10 ;
  int new_vel_in_max= 10 ;
  int vel_out_max= 15 ;
  int new_vel_out_max= 15 ;
  bool historic_data = false;
  String start_date = "";
  String start_time = "";
  String end_date = "";
  String end_time = "";
  String d_start_date = "";
  String d_start_time = "";
  String d_end_date = "";
  String d_end_time = "";
  String clave= "";
  bool del_data= false;
  float currentLat = 0;
  float currentLng = 0;
  float vel_sat = 0;

//Tren de comunicacion entre nucleos
  bool pack_ready = false;  //sirve para permitir que el core 0 coge el semaforo
  bool hasData = false;     //sirve para activar un if si el GPS no envio nada
  String jsonPayload;       //Data shared resources
  //Creamos un semaforo
  SemaphoreHandle_t xMutex;

//Configuración del cliente GSM y MQTT
  TinyGsm modem(sim800);
  TinyGsmClient gsmClient(modem);
  PubSubClient mqttClient(gsmClient);

void setup(){  
  xMutex=xSemaphoreCreateMutex();
  
  //Iniciar el puerto UART para la comunicacion con el GPS
  ss.begin(GPSBaud, SERIAL_8N1, GPSRXPin, GPSTXPin);
  
  //Iniciamos la LCD
  initializeLCD();
  
  //Iniciamos la comunicacion con la SIM800L
  initializeSIM();

  //Configuramos y nos conectamos al broker
  mqttClient.setServer(mqtt_server, mqtt_port);
  mqttClient.setCallback(callback);

  connectToMQTT();

  //Iniciamos la SD
  initializeSD();

  //Declaramos el pin de salida para el rele
  pinMode(ledvel,OUTPUT);
  //timeSet();//configuramos preferences para almacenar tiempo

  //Caracterizamos al core0
  xTaskCreatePinnedToCore(
    loop2,
    "Task_2",
    4096,
    NULL,
    1,
    &Task2,
    0);
  mqttClient.publish(topic6, ("Modulo "+String(client_id)+ " iniciado con exito").c_str());
}

void loop(){
  if (xSemaphoreTake(xMutex, portMAX_DELAY)){//Cojo el semaforo/banderin
    //"Escucho" por 1 segundo lo recibido por el GPS
    for (unsigned long start = millis(); millis() - start < 1000;){
      while (ss.available() > 0) {
        char c = ss.read();
        gps.encode(c);
        hasData=true;
      }
    }
    
    // Verifica si se ha recibido una nueva ubicación
    if (gps.location.isValid() && gps.location.isUpdated()) {
      displayInfo();//muestro en la LCD la velocidad
      saveDataToCSV();//guardo los datos de interes en la SD
      controlVel();//activo/desactivo el rele de control
      armedJson();//armo mi payload a ser enviado
      pack_ready= true;//habilito al loop2 a enviar
    }

    else if (!hasData){//Si el GPS no esta conectado
      lcd.clear();
      lcd.setCursor(0, 0);
      lcd.print("No hay GPS");
      mqttClient.publish(topic6, ("Fallo GPS en "+String(client_id)).c_str());
    }
    
    else {//Si el GPS no esta recibiendo la suficiente informacion
      lcd.clear();
      lcd.setCursor(0, 0);
      lcd.print("Captando señal ...");
      saveDataToCSV_off();
      armedJson();
      pack_ready= true;//habilito al loop2 a enviar datos repetidos
    }

    //funciones excepcionales
    if (new_vel_max){//Si se recibio por comando nuevas velocidades maximas
      lcd.clear();
      lcd.setCursor(0, 0);
      lcd.print("  Se cambiaron las  ");
      lcd.setCursor(0, 1);
      lcd.print("velocidades maximas:");
      lcd.setCursor(0, 2);
      lcd.print("Interna: ");
      lcd.print(new_vel_in_max);
      lcd.setCursor(0, 3);
      lcd.print("Externa: ");
      lcd.print(new_vel_out_max);
      //Se reescribe vel_max.txt
      new_config();
      readVel_max();
      new_vel_max= false;
    }

    if(del_data){//Si se recibio el comando de borrar datos
      lcd.clear();
      lcd.setCursor(0, 0);
      lcd.print("Borrando data");
      lcd.setCursor(0, 1);
      lcd.print("Historica");
      delete_SD();
      del_data= false;
    }

    //Han pasado 8 dias ?
    /*if (timeRead()) {
      mqttClient.publish(topic6, "¡Han pasado 8 días! Ejecutando acción.");
      File root = SD.open("/");
      // Leer todos los archivos en el directorio raíz
      File file = root.openNextFile();
      while (file) {
        String fileName = file.name(); // Obtener el nombre del archivo
        String Path = "/" + fileName;
        // Ignorar el archivo vel_max.txt
        if (fileName != "vel_max.txt") {

          // Eliminar el archivo
          SD.remove(fileName);
        }
        file = root.openNextFile(); // Siguiente archivo
      }
      root.close(); // Cerrar el directorio raíz
    }*/
    xSemaphoreGive(xMutex); //libero el mutex/semaforo/banderin
  }
}

void loop2(void *parameter) {
  TickType_t xLastWakeTime = xTaskGetTickCount();
  static bool mqtt_connected = false;
  for (;;) {
    // Intentar reconectar si no estamos conectados
    /*if (!mqtt_connected) {
      mqtt_connected = reconnectToMQTT(); // Intentar Reconectar a MQTT
      if (!mqtt_connected) {
        vTaskDelay(pdMS_TO_TICKS(2000)); // Esperar antes de volver a intentar
        continue; // Saltar if(pack_ready....) y volver a intentar reconnectMQTT()
      }
    }*/
    // Si el paquete está listo y estamos conectados al broker
    if (pack_ready) {
      if (xSemaphoreTake(xMutex, portMAX_DELAY)) { //el loop2 coje el mutex/semaforo/banderin
        // Enviar datos al broker MQTT
        sendToMQTTJson();
        //Funciones ocasionales
        if (historic_data) {
          lcd.clear();
          lcd.setCursor(0, 0);
          lcd.print("Enviando data");
          lcd.setCursor(0, 1);
          lcd.print("Historica");
          send_historic_data();
          historic_data = false;
        }
        xSemaphoreGive(xMutex); // Liberar el mutex/semaforo/banderin
        pack_ready = false; // Marcar el paquete como procesado
      }
    }
    // Intervalo fijo de espera para evitar saturar la CPU
    vTaskDelayUntil(&xLastWakeTime, pdMS_TO_TICKS(100));
  }
}

//Funcion de inicio de la LCD
void initializeLCD() {
  lcd.init();      // Inicializar la pantalla LCD
  lcd.backlight(); // Encender la retroiluminación
  big.begin();     //Habilitamos la libreria BigFont
  
  lcd.setCursor(0, 0);
  lcd.print("Iniciando...");
  delay(1000);
}

//Funcion de inicio del modulo SIM800L
void initializeSIM() {
  lcd.clear();
  lcd.setCursor(0, 0);
  lcd.print("Esperando SIM800");
  delay(1000);
  sim800.begin(SIMBaud, SERIAL_8N1, SIMRXPin, SIMTXPin);//configuramos la comunicacion con el SIM

  // Intentar iniciar el módem en un bucle
  while (!modem.restart()) {
    lcd.clear();
    lcd.setCursor(0, 0);
    lcd.print("Error al iniciar el módem");
    lcd.setCursor(0, 1);
    lcd.print("reintentando....");
    delay(2000);  // Espera 2 segundos antes de intentar nuevamente
  }

  lcd.clear();
  lcd.setCursor(0,0);
  lcd.println("SIM800 iniciado");
  delay(1000);

  // Intentar conectar a GPRS en bucle
  while (!modem.gprsConnect(APN, USER, PWD)  && attempt_apn_count < max_attempts) {
    attempt_apn_count++; 

    lcd.clear();
    lcd.setCursor(0, 0);
    lcd.print("Fallo configurando");
    lcd.setCursor(0, 1);
    lcd.print("APN");
    lcd.setCursor(0,2);
    lcd.print("reintentando....");
    delay(2000);  // Espera 2 segundos antes de intentar nuevamente
  }
  
  if(modem.gprsConnect(APN, USER, PWD)){
    lcd.clear();
    lcd.setCursor(0,0);
    lcd.print("APN configurado");
    delay(1000);
  }
  else {
    lcd.clear();
    lcd.setCursor(0,0);
    lcd.print("Fallo APN");
    delay(1000);
  }
}

//Configuracion Callback para recibir mensajes MQTT
void callback(char* topic, byte* payload, unsigned int length) {
  // Convertir el payload a String y mostrarlo
  String message;
  for (unsigned int i = 0; i < length; i++) {
    message += (char)payload[i];
  }

  StaticJsonDocument<256> doc;
  DeserializationError error = deserializeJson(doc, message);

  //Si hubo algun problema al deserializar el payload
  if (error) {
    
    mqttClient.publish(topic6, ("Error en "+String(client_id)+" al analizar el payload recibido").c_str());
    
    return;
  }

  //si el ID no se especifico o es no le corresponde
  if (!doc.containsKey("ID") || doc["ID"] != client_id) {
    
    mqttClient.publish(topic6, ("ID no coincide con "+String(client_id)).c_str());
    
    return;
  }
  
  String callback_use = "Mensaje recibido en " + String(client_id) + " desde el tópico: " + String(topic)+"\n";
  callback_use += "Contenido: ";
  mqttClient.publish(topic6, callback_use.c_str());

  // Enviar solo el payload en otro mensaje MQTT
  mqttClient.publish(topic6, message.c_str());
  
  // Procesar según el tópico
  if (strncmp(topic, topic2, strlen(topic2)) == 0) {   // Recibo 2 valores (vel_in_max y vel_out_max)
    if (doc.containsKey("vel_in_max") && doc.containsKey("vel_out_max")) {
      // Verifico que ambos valores sean enteros y positivos
      if (doc["vel_in_max"].is<int>() && doc["vel_in_max"] > 0 && doc["vel_out_max"].is<int>() && doc["vel_out_max"] > 0) {
        new_vel_max = true;
        // Extraigo las velocidades máximas válidas del payload recibido
        new_vel_in_max = doc["vel_in_max"];
        new_vel_out_max = doc["vel_out_max"];
      }
      else {

        mqttClient.publish(topic6, ("Valores inválidos registrados por "+String(client_id)+" en el topic "+String(topic2)).c_str());
     
      }
    }
    else {
     
      mqttClient.publish(topic6, ("Comando incorrecto registrado por "+String(client_id)+" en el topic "+String(topic2)).c_str());
   
    }
  }

  else if (strncmp(topic, topic3, strlen(topic3)) == 0) { // Recibo 2 fechas y 2 horas (YYYY-MM-DD y HH:MM:SS)
    if (doc.containsKey("start_date") && doc.containsKey("start_time") && doc.containsKey("end_date") && doc.containsKey("end_time")) {
      // Extraer los valores y verificar que sean cadenas
      String temp_start_date = doc["start_date"].as<String>();
      String temp_start_time = doc["start_time"].as<String>();
      String temp_end_date = doc["end_date"].as<String>();
      String temp_end_time = doc["end_time"].as<String>();

      // Validar formato de fecha y hora
      std::regex date_regex("^\\d{4}-\\d{2}-\\d{2}$");
      std::regex time_regex("^\\d{2}:\\d{2}:\\d{2}$");

      if (std::regex_match(temp_start_date.c_str(), date_regex) && std::regex_match(temp_start_time.c_str(), time_regex) && std::regex_match(temp_end_date.c_str(), date_regex) && std::regex_match(temp_end_time.c_str(), time_regex)) {

        historic_data = true;

        // Asignar los valores validados
        start_date = temp_start_date;
        start_time = temp_start_time;
        end_date = temp_end_date;
        end_time = temp_end_time;
      }
      else {

        mqttClient.publish(topic6, ("Formatos inválidos registrados por "+String(client_id)+" en el topic "+String(topic3)).c_str());
      
      }
    }
    else {

      mqttClient.publish(topic6, ("Comando incorrecto o rangos incompletos registrado por "+String(client_id)+" en el topic " + String(topic3)).c_str());
    
    }
  }
  
  else if (strncmp(topic, topic5, strlen(topic5)) == 0) { //ACA RECIBO 0 o 1 (1: borrar todos los datos de la SD)
    if(doc.containsKey("Clave")){ //verifico si se envio una clave de borrado
      clave= doc["Clave"].as<String>();
      //verifico que la clave sea del_SD sea valido para activar deleteSD()
      if (clave == del_SD){
        if (doc.containsKey("d_start_date") && doc.containsKey("d_start_time") &&
          doc.containsKey("d_end_date") && doc.containsKey("d_end_time")){
          // Extraer los valores y verificar que sean cadenas
          String temp_start_date = doc["d_start_date"].as<String>();
          String temp_start_time = doc["d_start_time"].as<String>();
          String temp_end_date = doc["d_end_date"].as<String>();
          String temp_end_time = doc["d_end_time"].as<String>();

          // Validar formato de fecha y hora
          std::regex date_regex("^\\d{4}-\\d{2}-\\d{2}$");
          std::regex time_regex("^\\d{2}:\\d{2}:\\d{2}$");

          if (std::regex_match(temp_start_date.c_str(), date_regex) &&
            std::regex_match(temp_start_time.c_str(), time_regex) &&
            std::regex_match(temp_end_date.c_str(), date_regex) &&
            std::regex_match(temp_end_time.c_str(), time_regex)) {

            del_data = true;

            // Asignar los valores validados
            d_start_date = temp_start_date;
            d_start_time = temp_start_time;
            d_end_date = temp_end_date;
            d_end_time = temp_end_time;

            String msg = "Borrando datos en "+String(client_id)+" desde:\n"+ d_start_date +" "+d_start_time +" hasta " +d_end_date+ " "+d_end_time;
          
            mqttClient.publish(topic6, msg.c_str());
          
          }
          else{

            mqttClient.publish(topic6, ("Formatos de fecha u hora inválidos ingresados a "+String(client_id)+" en el topic " + String(topic5)).c_str());

          }
        }
        else{
         
          mqttClient.publish(topic6, ("Rangos de borrado incompletos ingresados a "+String(client_id)+" en el topic "+String(topic5)).c_str());
        
        }
      }
      else{
        mqttClient.publish(topic6, ("Clave de borrado incorrecta ingresada en "+String(client_id)+" en el topic "+String(topic5)).c_str());
      }
    }
    else{
      mqttClient.publish(topic6, ("No se ingreso clave de borrado en "+String(client_id)+" en el topic "+String(topic5)).c_str());
    }
  }
}

// Función para conectar al broker MQTT (solo para setup)
void connectToMQTT() {
  // Configurar Keep Alive antes de conectar
  mqttClient.setKeepAlive(10);  // Configurar Keep Alive en 10s

  while (!mqttClient.connected() && attempt_connect_count < max_attempts) { // Reintentar hasta 3 veces
    attempt_connect_count++; // Incrementar contador de intentos
    
    if (mqttClient.connect(client_id, mqtt_user, mqtt_password, topiclwt, 0, true, lwt)) { // Configura la conexión al broker
      // Me suscribo a los tópicos donde recibiré información
      mqttClient.subscribe(topic2);
      mqttClient.subscribe(topic3);
      mqttClient.subscribe(topic5);

      // Grafico estado de conectado
      lcd.clear();
      lcd.setCursor(0, 0);
      lcd.print("Conectado a internet");
      
      mqttClient.publish(topic6, (String(client_id) + " conectado a internet").c_str());

      delay(1000);
      break; // Salir del bucle al conectar
    }
    else {
      lcd.clear();
      lcd.setCursor(0, 0);
      lcd.print("Fallo la conexion");
      lcd.setCursor(0, 1);
      lcd.print("a internet");
      lcd.setCursor(0, 2);
      lcd.print("Reintentando... ");
      delay(1000); // Espera antes de reintentar
    }
  }
}

//Funcion de inicio de SD
void initializeSD() {
  // Inicializar la tarjeta SD con reintento
  spiSD.begin(18, 19, 27, 5);
  while (!SD.begin(5, spiSD)) {
    lcd.clear();
    lcd.setCursor(0, 0);
    lcd.print("Error en SD");

    mqttClient.publish(topic6, ("Error de SD en "+String(client_id)).c_str());

    delay(1000);  // Esperar un momento antes de intentar de nuevo
  }

  // Confirmar que la tarjeta SD fue inicializada correctamente
  lcd.clear();
  lcd.setCursor(0, 0);
  lcd.print("SD inicializada");

  mqttClient.publish(topic6, ("SD Iniciada en "+String(client_id)).c_str());

  delay(1000);

  // Crear o abrir un archivo en la tarjeta SD
  SDFileCreation();
  //Leer la configuracion de velocidades
  readVel_max();
}
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
